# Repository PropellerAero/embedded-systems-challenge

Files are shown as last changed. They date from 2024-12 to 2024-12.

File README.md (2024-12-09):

# Propeller Embedded Systems Challenge

This is a small design task similar to the problems tackled by the Propeller hardware team. We want to see how you approach open ended problems and what you learn along the way. We are more interested in your process and critical thinking than the final result. If there is any ambiguity, make a note of any assumptions made and questions you would ask to resolve them.

## Background

Propeller Aero has recently decided to get into the consumer smart home devices market. Why? We have no idea, but it seemed like a good idea at the time. We've just finished designing the first product in this range, the Propeller LampMate™ and are eager to start manufacturing.

The LampMate is a small table lamp, it features:

- USB-C Power input
- WiFi control
- A warm white LED
- Not much else!

## The task

In this repository you will find the following design files for the LampMate main circuit board:

- `PropellerLampMate/` - The KiCAD EDA design project
- `PropellerLampMate.pdf` - The schematic drawing
- `PropellerLampMate_gerber/` - The PCB design in Gerber format
- `PropellerLampMate.png`- A 3D rendering of the layout

### Part A

This design has 10 intential errors in the schematic drawing and 8 in the PCB layout. Find as many as you can and write a couple of sentences for each explaining the problem, what impact it will have and how it should be fixed. Document these issues in whatever format you prefer (document, slide deck, marked up drawings) - focus on being as clear and succinct as possible.

### Part B

When we begin manufacturing the LampMate, the production team will need a programming and test procedure for this PCB. Device firmware will need to be loaded on to the microcontroller and the assembled PCB will need to be tested to ensure there are no assembly errors and it functions as expected.

Draw up a high-level design for a test including:

- A block diagram of any test fixture hardware required
- A process flow digram including the automated and manual steps to take freshly assembled PCBs in and output programmed and tested boards ready for final assembly
- Brief notes on each component and step

Consider in your design:

- Where will test points be required on the LampMate PCB to facilitate programming and testing?
- Which steps can be automated and which must be performed manually by an operator?
- How can we ensure the device functions as expected when the customer receives it?
- What kinds of assembly errors are likely? How can we catch these?
- How can we make this process as simple and fast as possible to minimise cost?

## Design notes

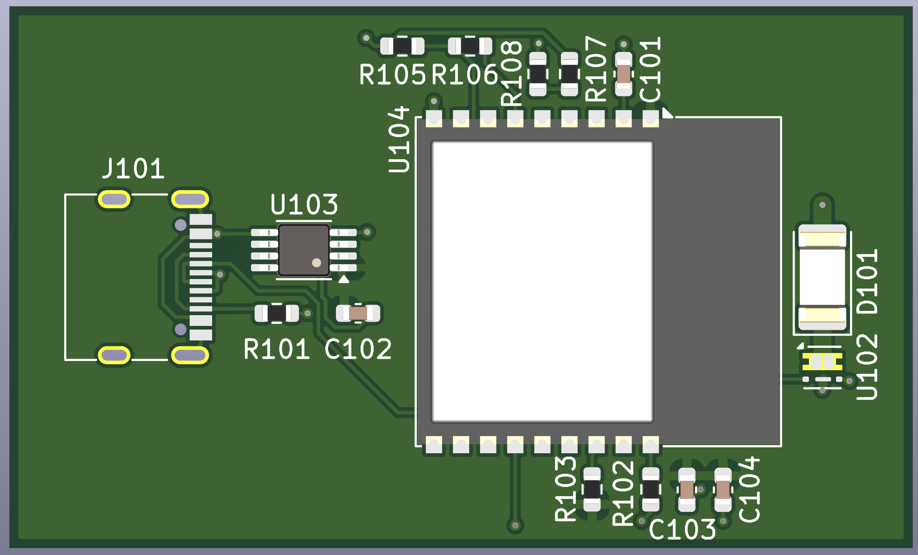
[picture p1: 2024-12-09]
PropellerLampMate.png

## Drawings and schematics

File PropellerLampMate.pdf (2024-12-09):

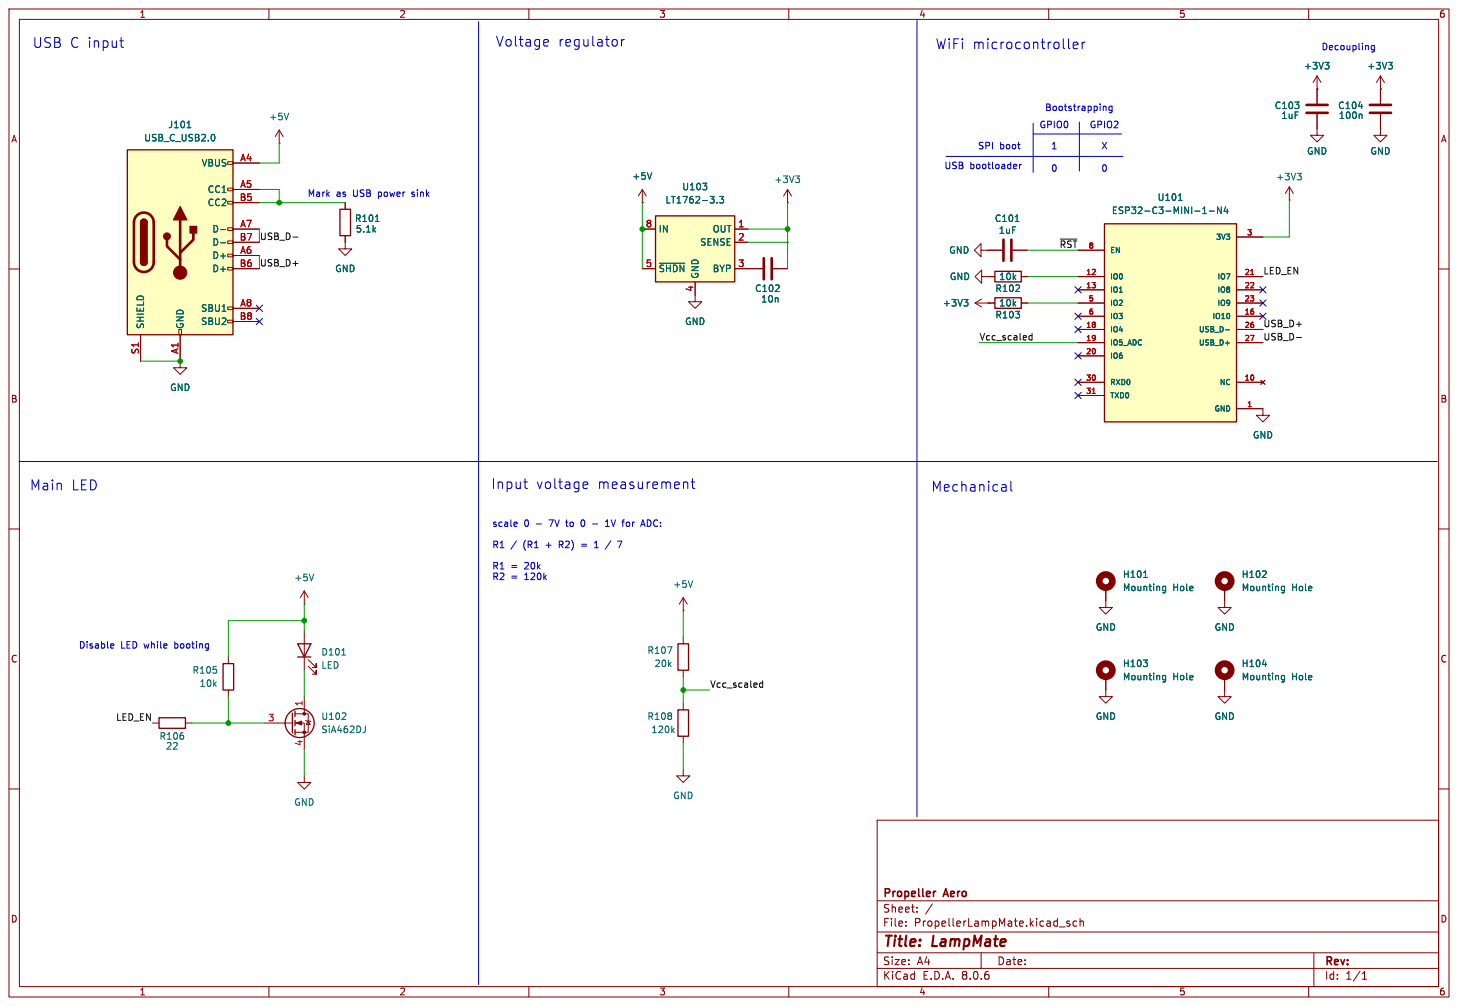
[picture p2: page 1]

0 Voltage regulator Disable LED while booting

USB bootloader SPI boot Main LED

File: PropellerLampMate.kicad_sch Sheet: / Propeller Aero

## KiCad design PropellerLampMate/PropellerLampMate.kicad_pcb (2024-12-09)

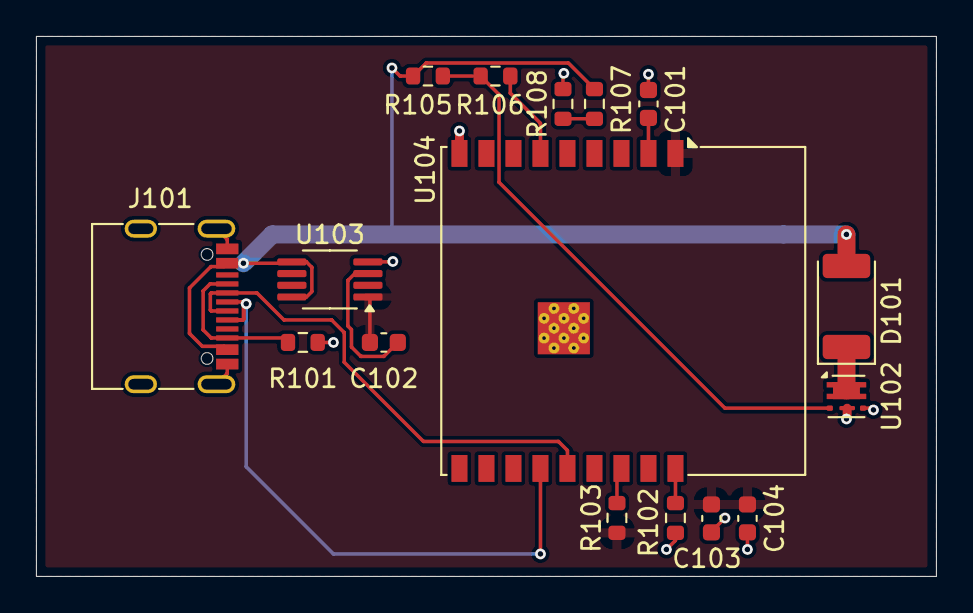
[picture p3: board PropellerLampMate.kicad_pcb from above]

Board: 2 copper layers, 50.0 x 30.0 mm, 16 parts (0 on the bottom side), 14 nets.

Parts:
C101, C103: 1uF; C_0603_1608Metric
C102: 10nF; C_0603_1608Metric
C104: 100nF; C_0603_1608Metric
D101: LED; LED_2010_5025Metric
J101: USB_C_USB2.0; USB_C_Receptacle_G-Switch_GT-USB-7010ASV
R101: 5.1k; R_0603_1608Metric
R102, R103, R105: 10k; R_0603_1608Metric
R106: 22; R_0603_1608Metric
R107: 20k; R_0603_1608Metric
R108: 120k; R_0603_1608Metric
U102: SiA462DJ; Vishay_PowerPAK_SC70-6L_Single
U103: LT1762-3.3; MSOP-8_3x3mm_P0.65mm
U104: ESP32-C3-WROOM-02

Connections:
+3V3: C102.2, C103.1, C104.1, R103.1, U103.1 (OUT), U104.1 (3V3)
+5V: D101.2 (A), J101.A4 (VBUS), J101.A9 (VBUS), J101.B4 (VBUS), J101.B9 (VBUS), R105.1, R107.1, U103.5 (~SHDN), U103.8 (IN)
/LED_EN: R106.1, U104.6 (IO7)
/USB_D+: J101.A6 (D+), J101.B6 (D+), U104.13 (USB_D-)
/USB_D-: J101.A7 (D-), J101.B7 (D-), U104.14 (USB_D+)
/Vcc_scaled: R107.2, R108.1, U104.4 (IO5_ADC)
/~RST: C101.1, U104.2 (EN)
GND: C101.2, C103.2, C104.2, J101.A1 (GND), J101.A12 (GND), J101.B1 (GND), J101.B12 (GND), J101.S1 (SHIELD), R101.2, R102.1, R108.2, U102.4 (S), U103.4 (GND), U104.9 (GND), U104.19 (GND)
unnamed: D101.1 (K), U102.1 (D)
unnamed: J101.A5 (CC1), J101.B5 (CC2), R101.1
unnamed: R105.2, R106.2, U102.3 (G)
unnamed: C102.1, U103.3 (BYP)
unnamed: R102.2, U104.18 (IO0)
unnamed: R103.2, U104.16 (IO2)

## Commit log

2024-12-09 Add reference PCB
    [PropellerLampMate.kicad_pcb, PropellerLampMate.kicad_sch]
2024-12-09 Add PDF / PNG / Gerbers
    [PropellerLampMate-B_Cu.gbl, PropellerLampMate-B_Mask.gbs, PropellerLampMate-B_Paste.gbp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]
2026-01-12 [DEP-1351] [skip ci] Adding Propeller Github standard files
    As part of SOC2 compliance we have implemented enforcement of standard files,
    including checks to ensure all GitHub Pull Requests are linked to a Jira card
    as a way to meet our obligation of always having changes documented and
    approved.
